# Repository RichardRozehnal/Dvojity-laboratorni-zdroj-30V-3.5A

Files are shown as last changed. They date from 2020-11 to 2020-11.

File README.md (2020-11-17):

# Dvojitý laboratorní zdroj 30V / 3.5A

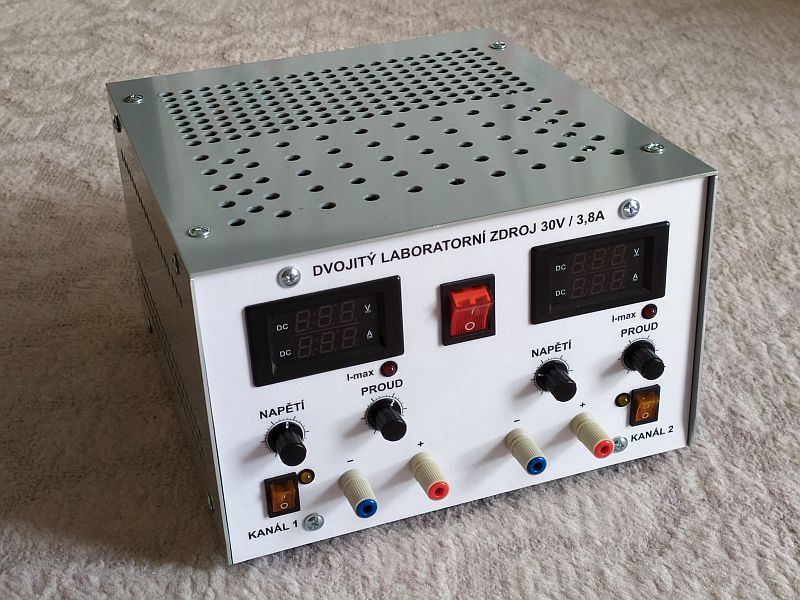
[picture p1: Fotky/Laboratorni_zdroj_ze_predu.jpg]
Dvojitý laboratorní zdroj 30V/3.5A


Napájecí zdroj s nastavitelným výstupním napětím 0-30V a nastavitelným omezením výstupního proudu 0-3.5A. Omezení proudu je indikováno červenou LEDkou.
Jedná se o dvoukanálový laboratorní zdroj.  Maximální proud, který jsem dostal z kanálu 1 je 3.5A a z kanálu 2 3.7A (po zkratování výstupních svorek).<br>
Použitý transformátor má několik sekundárních vinutí. Z nich jsem využil dvě hlavní, každé s výstupem 25V/4A a dvě pomocná s výstupem 12V/2A pro napájení panelových měřidel a ventilátorů.<br>
Zapnutí ventilátorů jsem nastavil na teplotu tranzistorů 60C, vypíná se při 46C.<br>
Čelní panel jsem nakreslil v Inkscape, vytiskl a potom přežehlil laminovací folií pro lepší vzhled, zpevnění a také ochranu tisku.<br>
Pro regulaci výstupního napětí a omezení proudu jsou použity 5-ti otáčkové potenciometry.<br>
Rozměr zdroje je 24cm x 15cm x 25cm, větrací otvory mají průměr 7mm a rozteč 10.4mm.

## Měření tvrdosti zdroje

| **nastavené napětí / napětí po zatížení (kanál 1 / kanál 2)** | **0.45A** | **0.89A** | **1.82A** | **3A** | **3.5A** |
| :---: | :---: | :---: | :---: | :---: | :---: |
| 5V | 5V / 5V | 5V / 5V | 5V / 5V | 5V / 5V | 5V / 5V |
| 10V | 10V / 10V | 10V / 10V | 10V / 10V | 10V / 10V | 10V / 10V |
| 20V | 20V / 20V | 20V / 20V | 20V /20V | 20V / 20V | 20V / 20V |
| 25V | | | | 24.5 V / 24.2V | 23.6V / 23.6V |
| 30V | 30V / 29.8V | 29V / 28.8V | 26.8V / 26.7V | | |

## Měření teplot a proudů (při otevřeném šasi)

| | nastavený proud  | Kanál 1  | Kanál 2  |
| --- | :---: | :---: | :---: |
| Teplota tranzistorů KD502 (bez zapnutého ventilátoru) | 1A | 54C | 58C |
| Teplota tranzistorů KD502 (bez zapnutého ventilátoru) | 2A | přes 70C | přes 80C |
| Teplota tranzistorů KD502 (se zapnutým ventilátorem)  | 2A | 55C | 63C |
| Teplota tranzistorů KD502 (se zapnutým ventilátorem)  | 3A | 65C | 76C |
| Teplota tranzistorů KD502 (se zapnutým ventilátorem)  | max. 3.5A / 3.7A | 67C | 84C |
| Teplota rezistorů R7 a R8 | 3A | 80C | 81C |
| Teplota rezistorů R7 a R8 | max. 3.5A / 3.7A | 92C | 107C |

## Seznam součástek

| **Ref** | **Qnty** | **Value** | **Cmp name** |
| --- | :---: | --- | --- |
| 230V1, | 1 | 230V | Conn\_01x02  |
| C1, C2, | 2 | 4700uF/63V/105C | CP |
| C3, C4, | 2 | 47uF/50V | CP |
| C5, | 1 | 220n CF1 | C |
| C6, C9, | 2 | 100pF | C |
| C7, | 1 | 10uF/50V | CP |
| C8, | 1 | 330pF | C |
| C10, C14, | 2 | 100nF | C |
| C13, | 1 | 330nF | C |
| C15, C16, | 2 | 1000uF/25V | CP |
| D1, D2, D3, D4, | 4 | P1000M | D |
| D5, D6, | 2 | 1N4148 | D |
| D7, | 1 | 1N4734A (5V6) | D\_Zener |
| D8, | 1 | BZX83V005.6 | D\_Zener |
| D9, D10, | 2 | 1N4148 | D |
| D11, D14, | 2 | S1M | D |
| D12, | 1 | LED 5mm červená | LED |
| D13, | 1 | KBP307 | KBP307 |
| D15, | 1 | LED 5mm žlutá | LED |
| F1, | 1 | 6A | Fuse |
| F2, | 1 | 500mA | Fuse |
| F3, | 1 | 2A | Fuse |
| IO1, IO2, IO3, | 3 | TL071 | TL071 |
| J1, | 1 | výstup na svorky | Conn\_01x02  |
| J2, | 1 | výstup na externí tranzistory | Conn\_01x03  |
| J3, | 1 | napájení panelového měřidla | Conn\_01x02  |
| M1, | 1 | ventilátor | Fan |
| P1, P2, | 2 | 10K (5ot.) | R\_Variable  |
| R1, | 1 | 2K2/2W | R |
| R2, | 1 | 220R | R |
| R3, | 1 | 82R | R |
| R4, R29, | 2 | 4K7 | R |
| R5, R6, R13, R20, R21, R28, R30, | 7 | 10K | R |
| R7, R8, | 2 | 1R0/10W | R |
| R9, R19, | 2 | 2K2 | R |
| R10, | 1 | 270K | R |
| R11, R25, | 2 | 27K | R |
| R12, R18, | 2 | 56K | R |
| R14, | 1 | 1K5 | R |
| R15, R16, R32, | 3 | 1K0 | R |
| R17, | 1 | 33R | R |
| R22, | 1 | 1K8 | R |
| R23, R24, | 2 | 0R33/5W | R |
| R26, | 1 | 100K | RTRIM |
| R27, | 1 | 10K | RTRIM |
| R31, | 1 | 1M5 | R |
| R33, | 1 | 1K8 | R |
| SW1, | 1 | Hlavní vypínač | SW\_DPST |
| SW2, | 1 | Vypínač | SW\_DPST\_2  |
| T1, T2, T6, | 3 | MMBT2222 | Q\_NPN\_BEC  |
| T3, | 1 | BC857 | Q\_PNP\_BEC  |
| T4, T5, | 2 | KD502 | Q\_NPN\_BEC  |
| TH1, | 1 | KTY81-210 | KTY81 |
| TR1, | 1 | Trafo | Trafo |
| U2, | 1 | L7812 | L7812 |
| U3, | 1 | LM358 | LM358 |
| | | | |
| | 2 | hmatník na potenciometry | |
| | 2 | konektor, banánky | |
| | 2 | mřižka na ventilátor | |
| | 1 | chladič S25AN (15C/W) na TO-220 (L7812) | |
| | 1 | panelové měřidlo | |
| | 1 | chladič pro KD502 | |

## Další obrázky

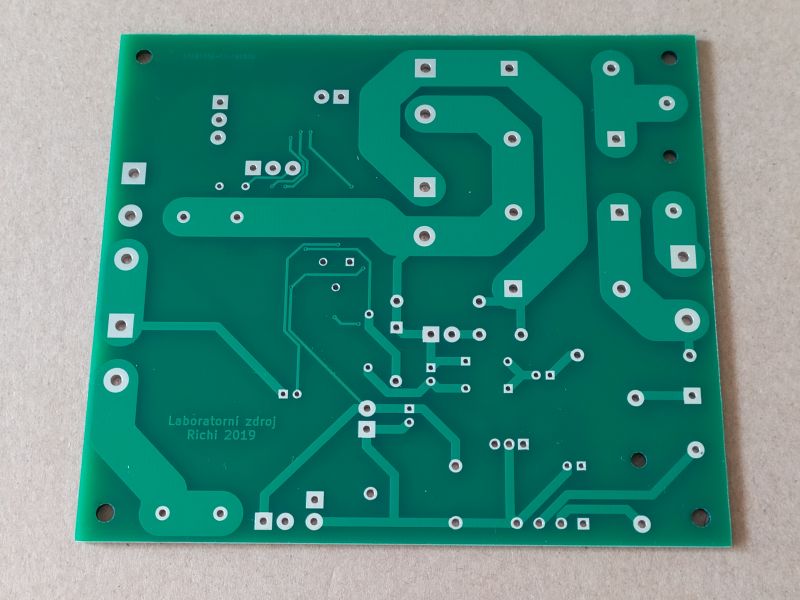
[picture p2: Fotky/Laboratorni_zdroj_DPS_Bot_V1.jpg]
Laboratorní zdroj DPS Bot V1

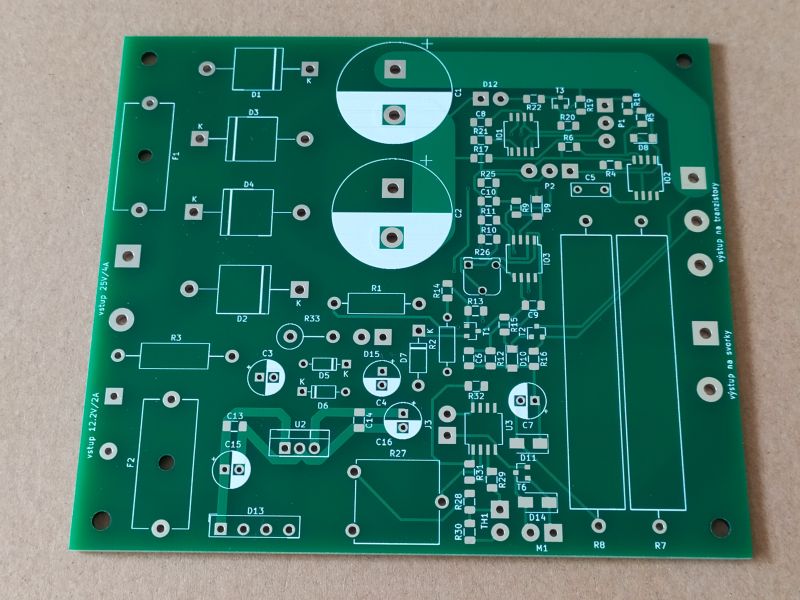
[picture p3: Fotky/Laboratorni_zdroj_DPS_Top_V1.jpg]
Laboratorní zdroj DPS Top V1

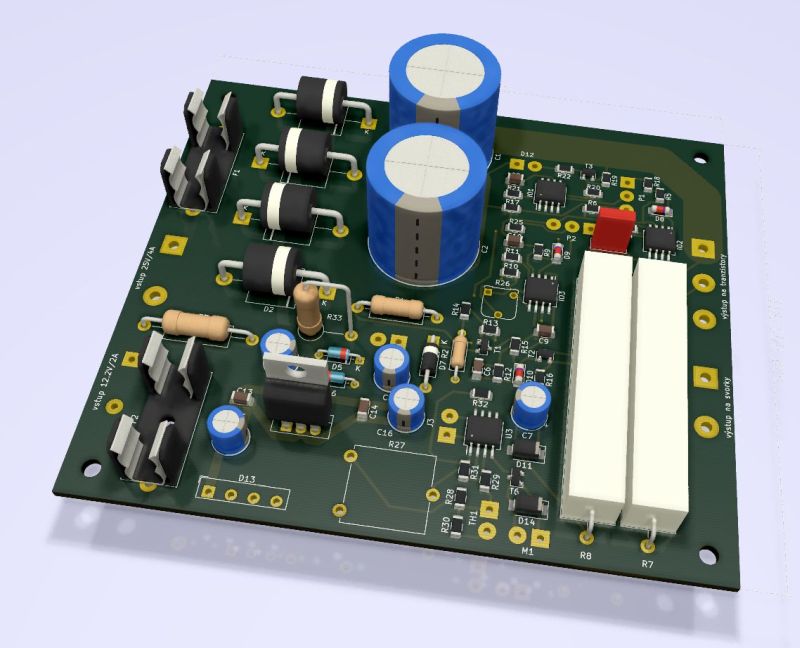
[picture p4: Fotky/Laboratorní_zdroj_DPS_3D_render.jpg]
Laboratorní zdroj DPS 3D render

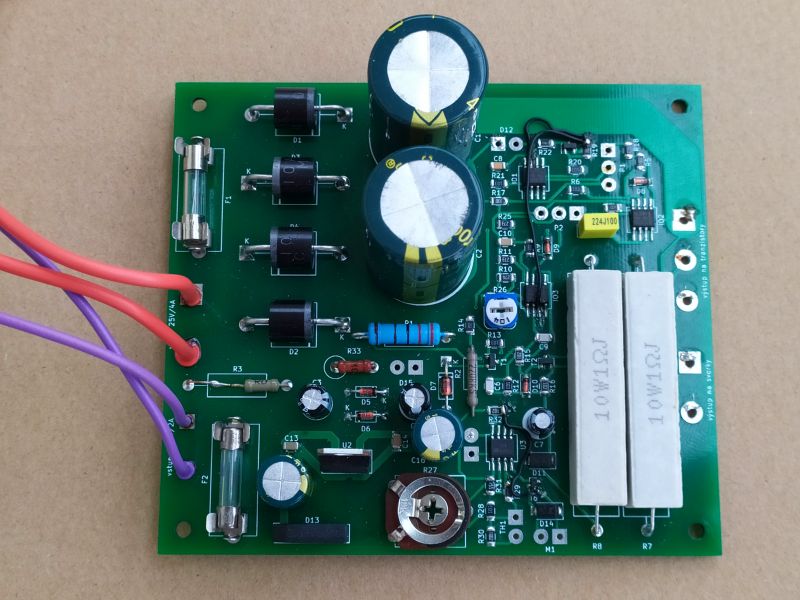
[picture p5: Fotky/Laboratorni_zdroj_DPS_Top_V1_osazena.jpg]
Laboratorní zdroj DPS Top V1 osazená

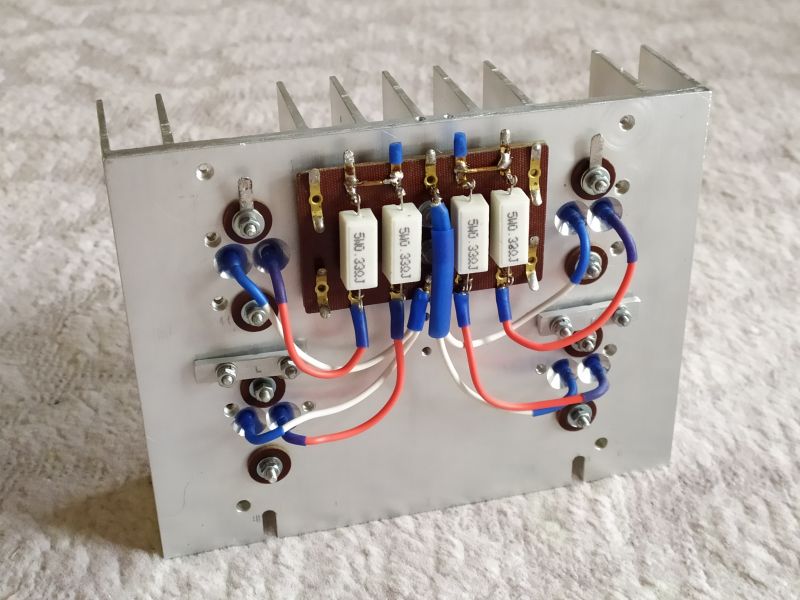
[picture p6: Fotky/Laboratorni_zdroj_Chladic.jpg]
Laboratorní zdroj - Chladič

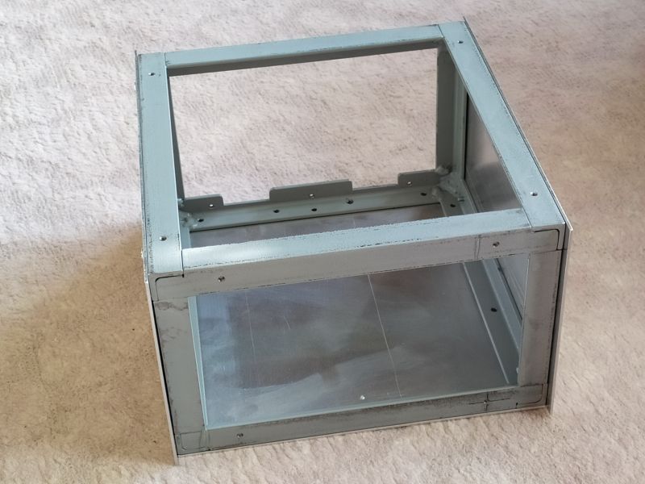
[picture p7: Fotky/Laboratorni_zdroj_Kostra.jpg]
Laboratorní zdroj - Kostra

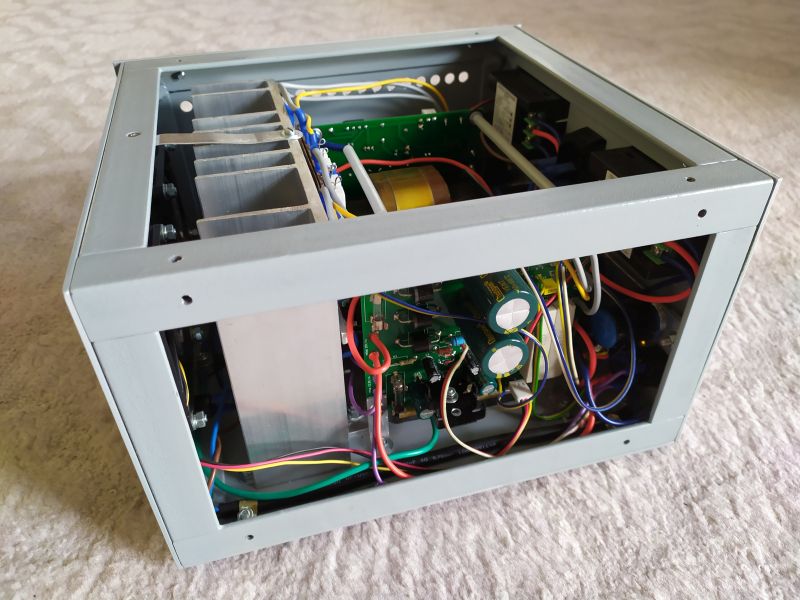
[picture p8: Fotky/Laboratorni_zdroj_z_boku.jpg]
Laboratorní zdroj z boku

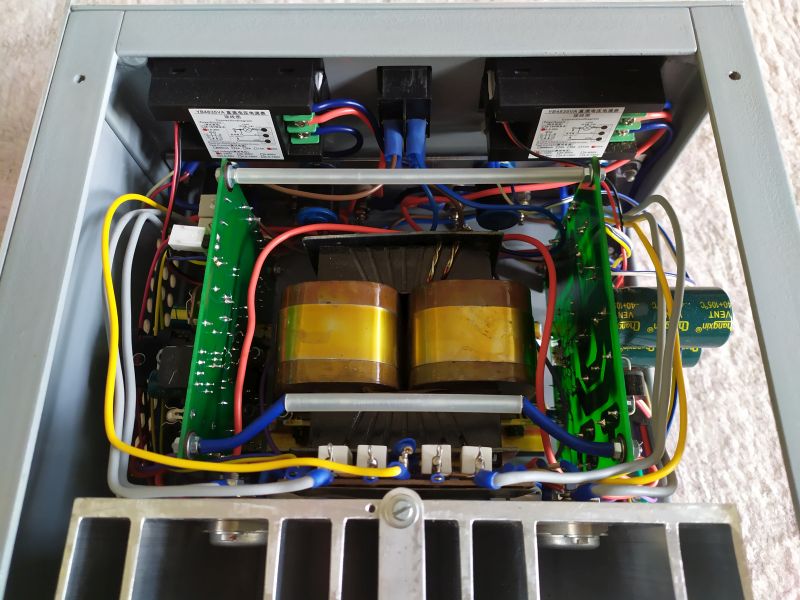
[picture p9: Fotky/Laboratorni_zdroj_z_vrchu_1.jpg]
Laboratorní zdroj z vrchu 1

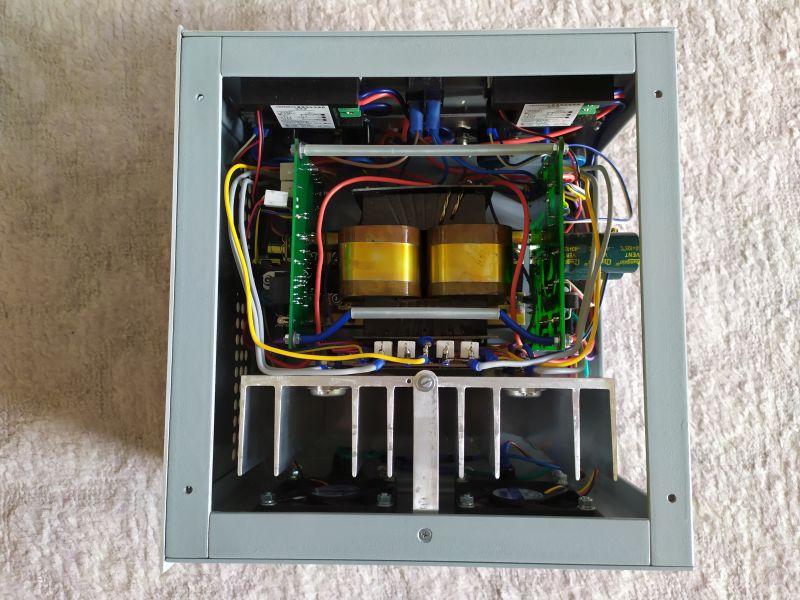
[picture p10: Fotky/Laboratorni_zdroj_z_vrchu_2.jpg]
Laboratorní zdroj z vrchu 2

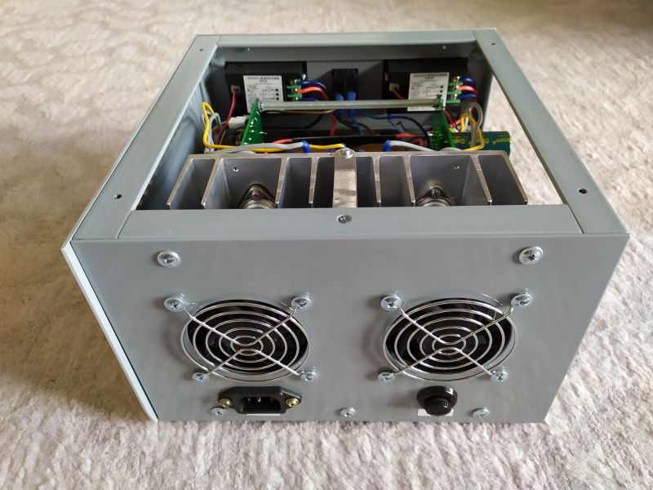
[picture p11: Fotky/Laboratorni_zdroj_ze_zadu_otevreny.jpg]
Laboratorní zdroj ze zadu otevřený

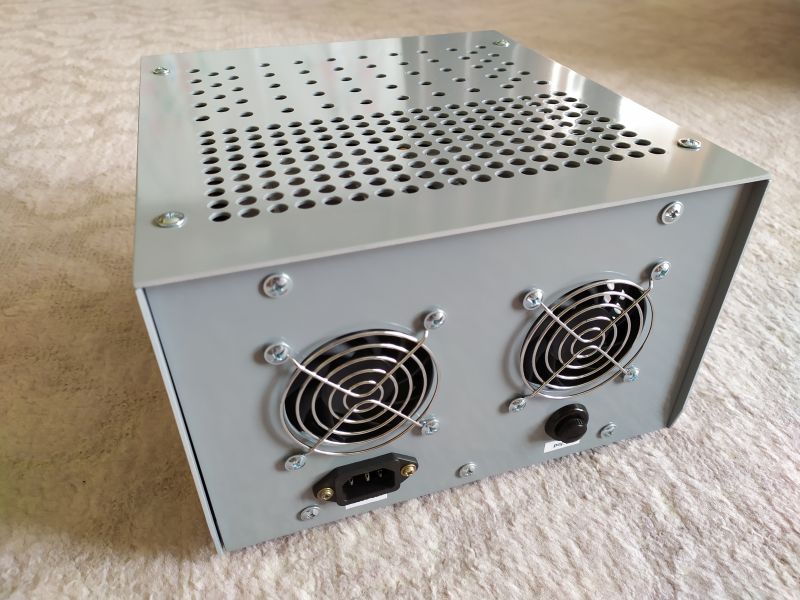
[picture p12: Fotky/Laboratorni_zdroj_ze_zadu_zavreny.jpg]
Laboratorní zdroj ze zadu zavřený


Původní zapojení, ze kterého jsem vycházel, je [tady](http://bcmp.cz/laboratorni-zdroj-0-30v-2ma-4a/).

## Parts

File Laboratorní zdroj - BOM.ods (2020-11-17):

Laboratorní zdroj 30V/3.5A – BOM
Ref | Qnty | Value | Cmp name | Footprint
230V1, | 1 | 230V | Conn_01x02
C1, C2, | 2 | 4700uF/63V/105C | CP | CP_Radial_D22.0mm_P10.00mm_SnapIn
C3, C4, | 2 | 47uF/50V | CP | CP_Radial_D6.3mm_P2.50mm
C5, | 1 | 220n CF1 | C | C_Rect_L7.0mm_W2.5mm_P5.00mm
C6, C9, | 2 | 100pF | C | C_1206_3216Metric
C7, | 1 | 10uF/50V | CP | CP_Radial_D6.3mm_P2.50mm
C8, | 1 | 330pF | C | C_1206_3216Metric
C10, C14, | 2 | 100nF | C | C_1206_3216Metric
C13, | 1 | 330nF | C | C_1206_3216Metric
C15, C16, | 2 | 1000uF/25V | CP | CP_Radial_D10.0mm_P5.00mm
D1, D2, D3, D4, | 4 | P1000M | D | D_P600_R-6_P20.00mm_Horizontal
D5, D6, | 2 | 1N4148 | D | D_DO-35_SOD27_P7.62mm_Horizontal
D7, | 1 | 1N4734A (5V6) | D_Zener | D_DO-41_SOD81_P10.16mm_Horizontal
D8, | 1 | BZX83V005.6 | D_Zener | D_MiniMELF
D9, D10, | 2 | 1N4148 | D | D_MiniMELF
D11, D14, | 2 | S1M | D | D_SMA
D12, | 1 | LED 5mm červená | LED | SolderWirePad_1x02_P3.81mm_Drill1.2mm
D13, | 1 | KBP307 | KBP307 | Diode_Bridge_KBP307_15.0x3.5x10.0mm_P4.0mm
D15, | 1 | LED 5mm žlutá | LED | SolderWirePad_1x02_P3.81mm_Drill1.2mm
F1, | 1 | 6A | Fuse | Fuseholder_Cylinder-5x20mm_Schurter_0031_8201_Horizontal_Open
F2, | 1 | 500mA | Fuse | Fuseholder_Cylinder-5x20mm_Schurter_0031_8201_Horizontal_Open
F3, | 1 | 2A | Fuse
IO1, IO2, IO3, | 3 | TL071 | TL071 | SO-8_5.3x6.2mm_P1.27mm
J1, | 1 | výstup na svorky | Conn_01x02 | SolderWirePad_1x02_P10.414mm_Drill2mm
J2, | 1 | výstup na externí tranzistory | Conn_01x03 | SolderWirePad_1x03_P5.715mm_Drill2mm
J3, | 1 | napájení panelového měřidla | Conn_01x02 | SolderWirePad_1x02_P3.81mm_Drill1.2mm
M1, | 1 | ventilátor | Fan | SolderWirePad_1x02_P3.81mm_Drill1.2mm
P1, P2, | 2 | 10K (5ot.) | R_Variable | SolderWirePad_1x03_P3.81mm_Drill1.2mm
R1, | 1 | 2K2/2W | R | R_Axial_DIN0614_L14.3mm_D5.7mm_P20.32mm_Horizontal
R2, | 1 | 220R | R | R_Axial_DIN0207_L6.3mm_D2.5mm_P10.16mm_Horizontal
R3, | 1 | 82R | R | R_Axial_DIN0414_L11.9mm_D4.5mm_P20.32mm_Horizontal
R4, R29, | 2 | 4K7 | R | R_1206_3216Metric
R5, R6, R13, R20, R21, R28, R30, | 7 | 10K | R | R_1206_3216Metric
R7, R8, | 2 | 1R0/10W | R | R_Axial_Power_L50.0mm_W9.0mm_P55.88mm
R9, R19, | 2 | 2K2 | R | R_1206_3216Metric
R10, | 1 | 270K | R | R_1206_3216Metric
R11, R25, | 2 | 27K | R | R_1206_3216Metric
R12, R18, | 2 | 56K | R | R_1206_3216Metric
R14, | 1 | 1K5 | R | R_1206_3216Metric
R15, R16, R32, | 3 | 1K0 | R | R_1206_3216Metric
R17, | 1 | 33R | R | R_1206_3216Metric
R22, | 1 | 1K8 | R | R_1206_3216Metric
R23, R24, | 2 | 0R33/5W | R
R26, | 1 | 100K | RTRIM | Potentiometer_Runtron_RM-065_Vertical
R27, | 1 | 10K | RTRIM | Potentiometer_ACP_CA14V-15_Vertical
R31, | 1 | 1M5 | R | R_1206_3216Metric
R33, | 1 | 1K8 | R | R_Axial_DIN0207_L6.3mm_D2.5mm_P10.16mm_Horizontal
SW1, | 1 | Hlavní vypínač | SW_DPST
SW2, | 1 | Vypínač | SW_DPST_2
T1, T2, T6, | 3 | MMBT2222 | Q_NPN_BEC | SOT-23
T3, | 1 | BC857 | Q_PNP_BEC | SOT-23
T4, T5, | 2 | KD502 | Q_NPN_BEC
TH1, | 1 | KTY81-210 | KTY81 | SolderWirePad_1x02_P3.81mm_Drill1.2mm
TR1, | 1 | Trafo | Trafo | Trafo
U2, | 1 | L7812 | L7812 | TO-220-3_Vertical
U3, | 1 | LM358 | LM358 | SO-8_5.3x6.2mm_P1.27mm
 | 2 | hmatník na potenciometry
 | 2 | konektor, banánky |  | červený a modrý
 | 2 | mřižka na ventilátor
 | 1 | chladič S25AN (15C/W) na TO-220 (L7812)
 | 1 | panelové měřidlo
 | 1 | chladič pro KD502

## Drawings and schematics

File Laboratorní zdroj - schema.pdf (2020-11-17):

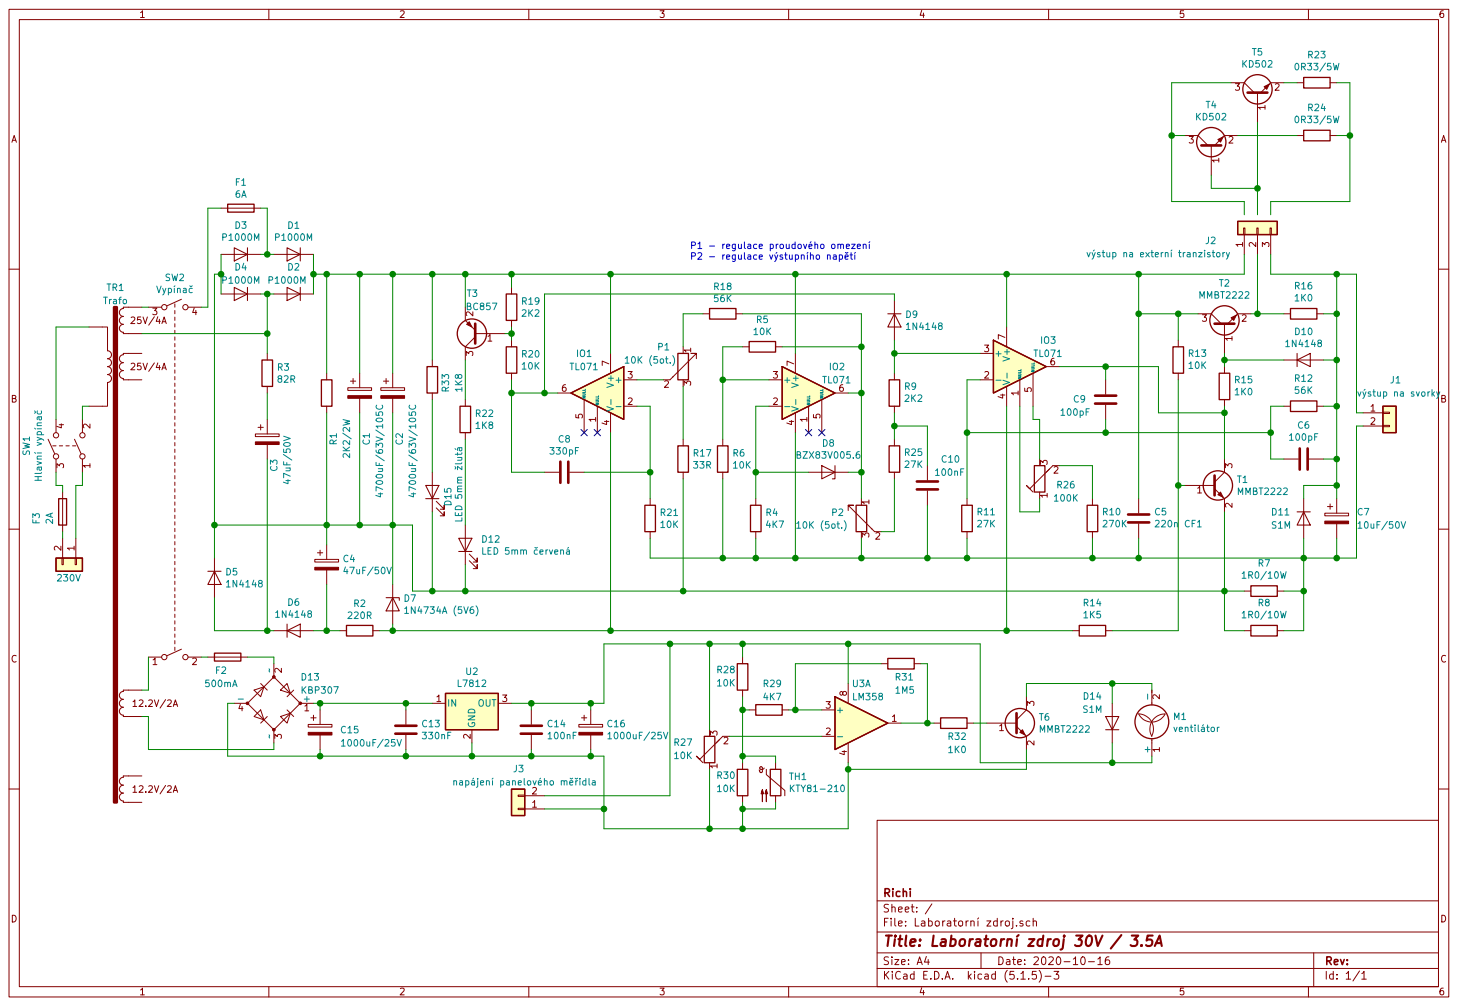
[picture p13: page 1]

File: Laboratorní zdroj.sch Sheet: / Richi R4

Id: 1/1 Title: Laboratorní zdroj 30V / 3.5A

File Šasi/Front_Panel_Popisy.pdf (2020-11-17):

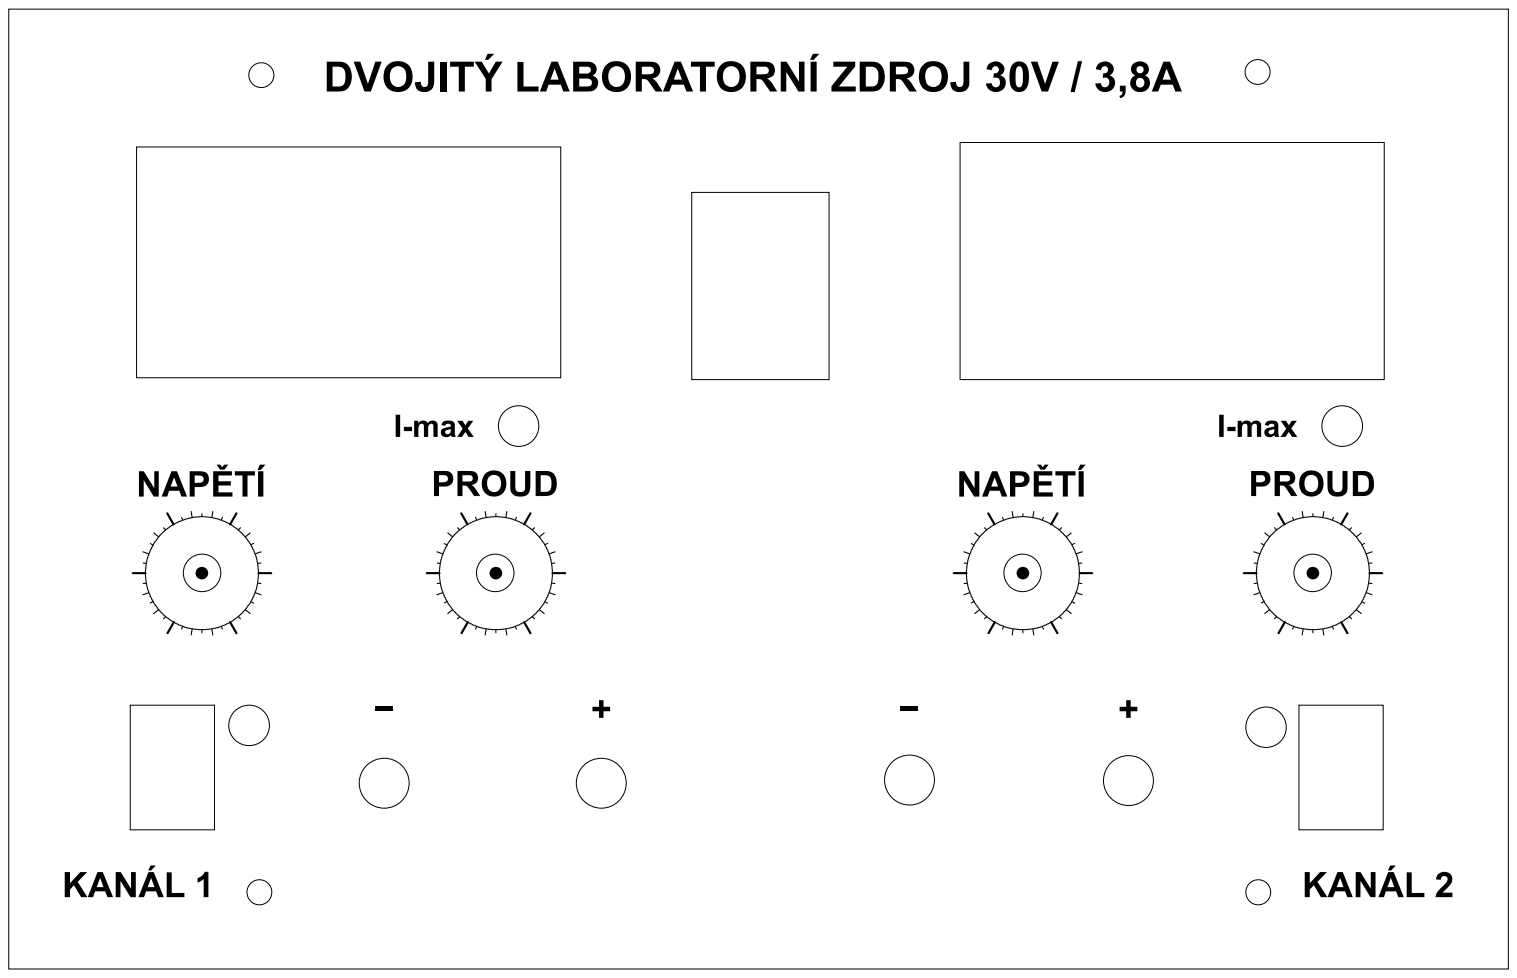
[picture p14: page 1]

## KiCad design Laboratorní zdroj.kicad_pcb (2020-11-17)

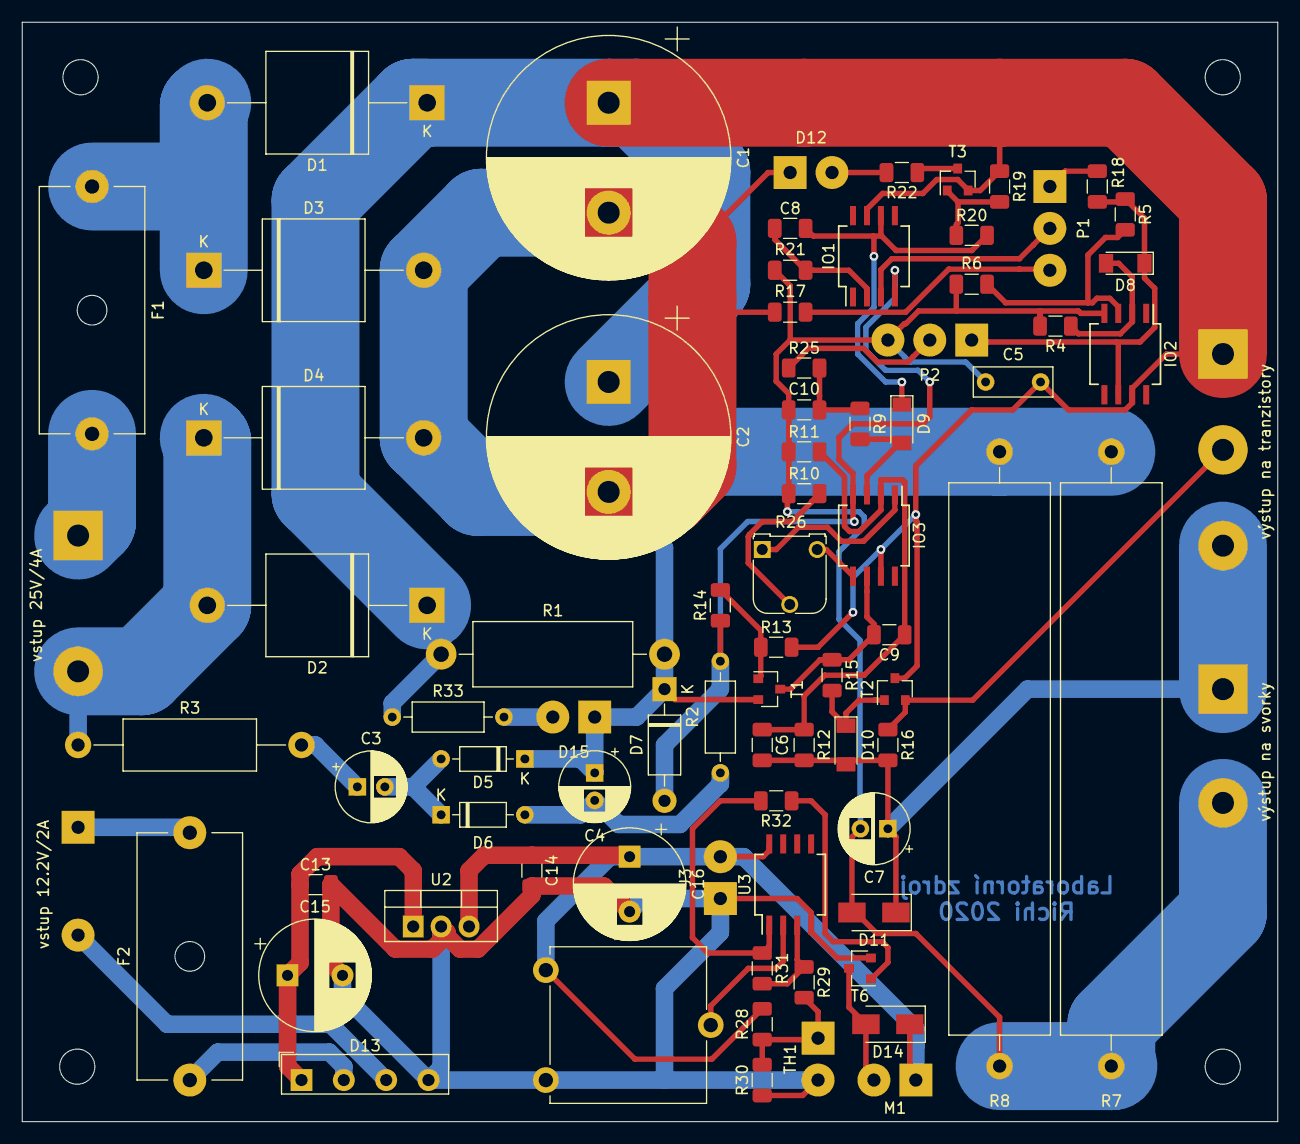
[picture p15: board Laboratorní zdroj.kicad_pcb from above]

Board: 2 copper layers, 114.2 x 100.0 mm, 79 parts (0 on the bottom side), 44 nets.

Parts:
C1, C2: 4700uF/63V/105C; CP_Radial_D22.0mm_P10.00mm_SnapIn
C3, C4: 47uF/50V; CP_Radial_D6.3mm_P2.50mm
C5: 220n CF1; C_Rect_L7.0mm_W2.5mm_P5.00mm
C6, C9: 100pF; C_1206_3216Metric
C7: 10uF/50V; CP_Radial_D6.3mm_P2.50mm
C8: 330pF; C_1206_3216Metric
C10, C14: 100nF; C_1206_3216Metric
C13: 330nF; C_1206_3216Metric
C15, C16: 1000uF/25V; CP_Radial_D10.0mm_P5.00mm
D1, D2, D3, D4: P1000M; D_P600_R-6_P20.00mm_Horizontal
D5, D6: 1N4148; D_DO-35_SOD27_P7.62mm_Horizontal
D7: 1N4734A (5V6); D_DO-41_SOD81_P10.16mm_Horizontal
D8: BZX83V005.6; D_MiniMELF
D9, D10: 1N4148; D_MiniMELF
D11, D14: S1M; D_SMA
D12: LED 5mm červená; SolderWirePad_1x02_P3.81mm_Drill1.2mm
D13: KBP307; Diode_Bridge_KBP307_15.0x3.5x10.0mm_P4.0mm
D15: LED 5mm žlutá; SolderWirePad_1x02_P3.81mm_Drill1.2mm
F1: 6A; Fuseholder_Cylinder-5x20mm_Schurter_0031_8201_Horizontal_Op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
F2: 500mA; Fuseholder_Cylinder-5x20mm_Schurter_0031_8201_Horizontal_Op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
IO1, IO2, IO3: TL071; SO-8_5.3x6.2mm_P1.27mm
J3: napájení panelového měřidla; SolderWirePad_1x02_P3.81mm_Drill1.2mm
M1: ventilátor; SolderWirePad_1x02_P3.81mm_Drill1.2mm
P1, P2: 10K (5ot.); SolderWirePad_1x03_P3.81mm_Drill1.2mm
R1: 2K2/2W; R_Axial_DIN0614_L14.3mm_D5.7mm_P20.32mm_Horizontal
R2: 220R; R_Axial_DIN0207_L6.3mm_D2.5mm_P10.16mm_Horizontal
R3: 82R; R_Axial_DIN0414_L11.9mm_D4.5mm_P20.32mm_Horizontal
R4, R29: 4K7; R_1206_3216Metric
R5, R6, R13, R20, R21, R28, R30: 10K; R_1206_3216Metric
R7, R8: 1R0/10W; R_Axial_Power_L50.0mm_W9.0mm_P55.88mm
R9, R19: 2K2; R_1206_3216Metric
R10: 270K; R_1206_3216Metric
R11, R25: 27K; R_1206_3216Metric
R12, R18: 56K; R_1206_3216Metric
R14: 1K5; R_1206_3216Metric
R15, R16, R32: 1K0; R_1206_3216Metric
R17: 33R; R_1206_3216Metric
R22: 1K8; R_1206_3216Metric
R26: 100K; Potentiometer_Runtron_RM-065_Vertical
R27: 10K; Potentiometer_ACP_CA14V-15_Vertical
R31: 1M5; R_1206_3216Metric
R33: 1K8; R_Axial_DIN0207_L6.3mm_D2.5mm_P10.16mm_Horizontal
T1, T2, T6: MMBT2222; SOT-23
T3: BC857; SOT-23
TH1: KTY81-210; SolderWirePad_1x02_P3.81mm_Drill1.2mm
U2: L7812; TO-220-3_Vertical
U3: LM358; SO-8_5.3x6.2mm_P1.27mm
vstup 25V/4A: Trafo
výstup na svorky: výstup na svorky; SolderWirePad_1x02_P10.414mm_Drill2mm
výstup na tranzistory: výstup na externí tranzistory; SolderWirePad_1x03_P5.715mm_Drill2mm

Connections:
unnamed: C1.1, C2.1, C5.2, D1.1, D2.1, IO1.7, IO2.7, IO3.7, R1.1, R13.2, R19.1, R33.1, T2.3, T3.2, výstup na tranzistory.1
unnamed: C1.2, C2.2, C4.1, D3.2, D4.2, D5.1, D7.1, D12.1, D15.1, R1.2, R7.1, R8.1, R17.2, T1.2
unnamed: C3.1, R3.2
unnamed: C3.2, D5.2, D6.1
unnamed: C4.2, D6.2, R2.2
unnamed: C6.1, C9.1, IO3.2, R11.2, R12.1
unnamed: C6.2, C7.1, D10.2, D11.1, R12.2, R16.2, výstup na svorky.1, výstup na tranzistory.3
unnamed: C8.1, IO1.2, R21.1
unnamed: C8.2, D9.1, IO1.6, R20.2
unnamed: C9.2, IO3.6, R15.1, T1.3
unnamed: C10.1, R9.1, R25.2
unnamed: C5.1, C7.2, C10.2, D11.2, IO2.4, P2.3, R4.2, R6.2, R7.2, R8.2, R10.1, R11.1, R21.2, výstup na svorky.2
unnamed: C13.1, C15.1, D13.1, U2.1
unnamed: C13.2, C14.2, C15.2, C16.2, D13.4, J3.1, R27.1, R30.1, T6.2, TH1.2, U2.2, U3.4
unnamed: C14.1, C16.1, D14.1, J3.2, M1.1, R27.3, R28.2, U2.3, U3.8
unnamed: D1.2, D3.1, F1.1
unnamed: D2.2, D4.1, R3.1, vstup 25V/4A.4
unnamed: D7.2, IO1.4, IO3.4, R2.1, R14.1
unnamed: D8.1, IO2.6, P2.1, R5.1, R18.1
unnamed: D8.2, IO2.2, R4.1
unnamed: D9.2, IO3.3, R9.2
unnamed: D10.1, R15.2, T2.1
unnamed: D12.2, R22.2
unnamed: D13.2, F2.1
unnamed: D13.3, vstup 25V/4A.8
unnamed: D14.2, M1.2, T6.3
unnamed: D15.2, R33.2
unnamed: IO1.3, P1.2
unnamed: IO2.3, R5.2, R6.1
unnamed: IO3.1, R26.1
unnamed: IO3.5, R26.3
unnamed: R16.1, T2.2, výstup na tranzistory.2
unnamed: P1.1, R18.2
unnamed: P1.3, R17.1
unnamed: P2.2, R25.1
unnamed: R10.2, R26.2
unnamed: R13.1, R14.2, T1.1
unnamed: R19.2, R20.1, T3.1
unnamed: R22.1, T3.3
unnamed: R27.2, U3.2
unnamed: R28.1, R29.2, R30.2, TH1.1
unnamed: R29.1, R31.2, U3.3
unnamed: R31.1, R32.2, U3.1
unnamed: R32.1, T6.1
